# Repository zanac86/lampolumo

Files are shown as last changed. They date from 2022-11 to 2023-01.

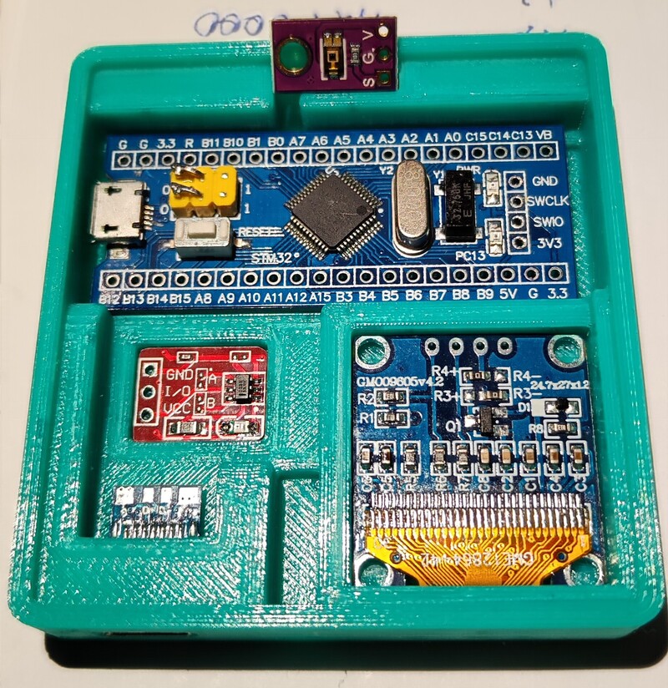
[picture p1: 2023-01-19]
docs/foto1.jpg

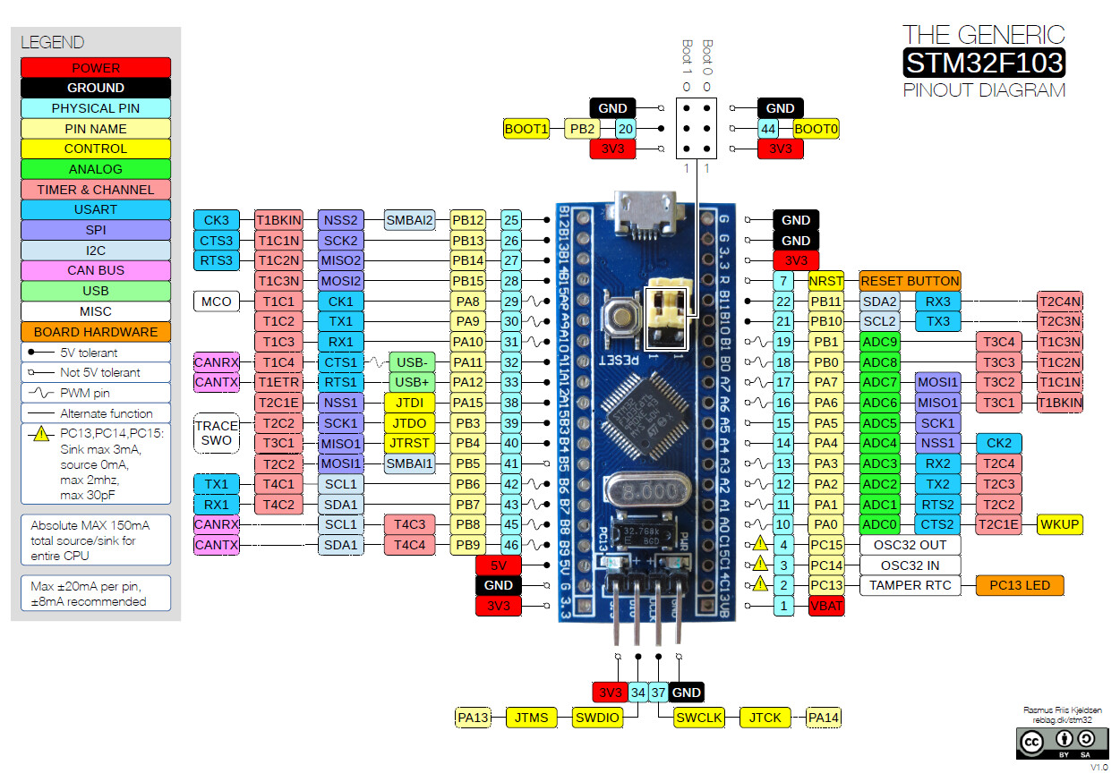
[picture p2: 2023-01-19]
docs/bluepill_pins.jpg

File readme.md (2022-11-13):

# Lampo Lumo (lamp light, esperanto)

Measure pulsation of lamp light

Original project https://mysku.ru/blog/diy/90736.html

## Connection

### OLED SSD1306 display on I2C

| STM | OLED |
|-----|---|
| 3.3 | VDD  |
| GND | GND  |
| B6  | SCK  |
| B7  | SDA  |

### TEMT6000 ambient light sensor to ADC1:0

| STM | TEMT6000 |
|-----|---|
| 5V  | V |
| GND | G |
| A0  | S |

## Firmware upload with `STM32CubeProgrammer`

```
cd /d D:\ST\STM32Cube\STM32CubeProgrammer\bin\
STM32_Programmer_CLI.exe -c port=SWD -d lampo.elf -rst -run
```

## Timings

Ext 8MHz -> HCLK 72 Mhz

APB1 Timer clocks = 72 Mhz
APB2 Timer clocks = 72 Mhz

таймеры TIM2, TIM3, TIM4 работают от APB1 

Это не период между семплами, а время преобразования
зависит от тактовой частоты подаваемой на АЦП
ADC1 = 9 Mhz
а время преобразования задается в тиках этой частоты
ADC1 conversion time - 71.5 cycles - 7,94444 us

BUF - 3000 samples
Sample ADC read period - 100 us - 10 kHz
Fill time - 0.6 s

TIM2 - 1 s

Период между сбором семплов АЦП
TIM3 - 
делители 144-1, 50-1  - 10000 кГц - 100.0 мкс
делители 225-1, 100-1 -  3200 кГц - 312.5 мкс

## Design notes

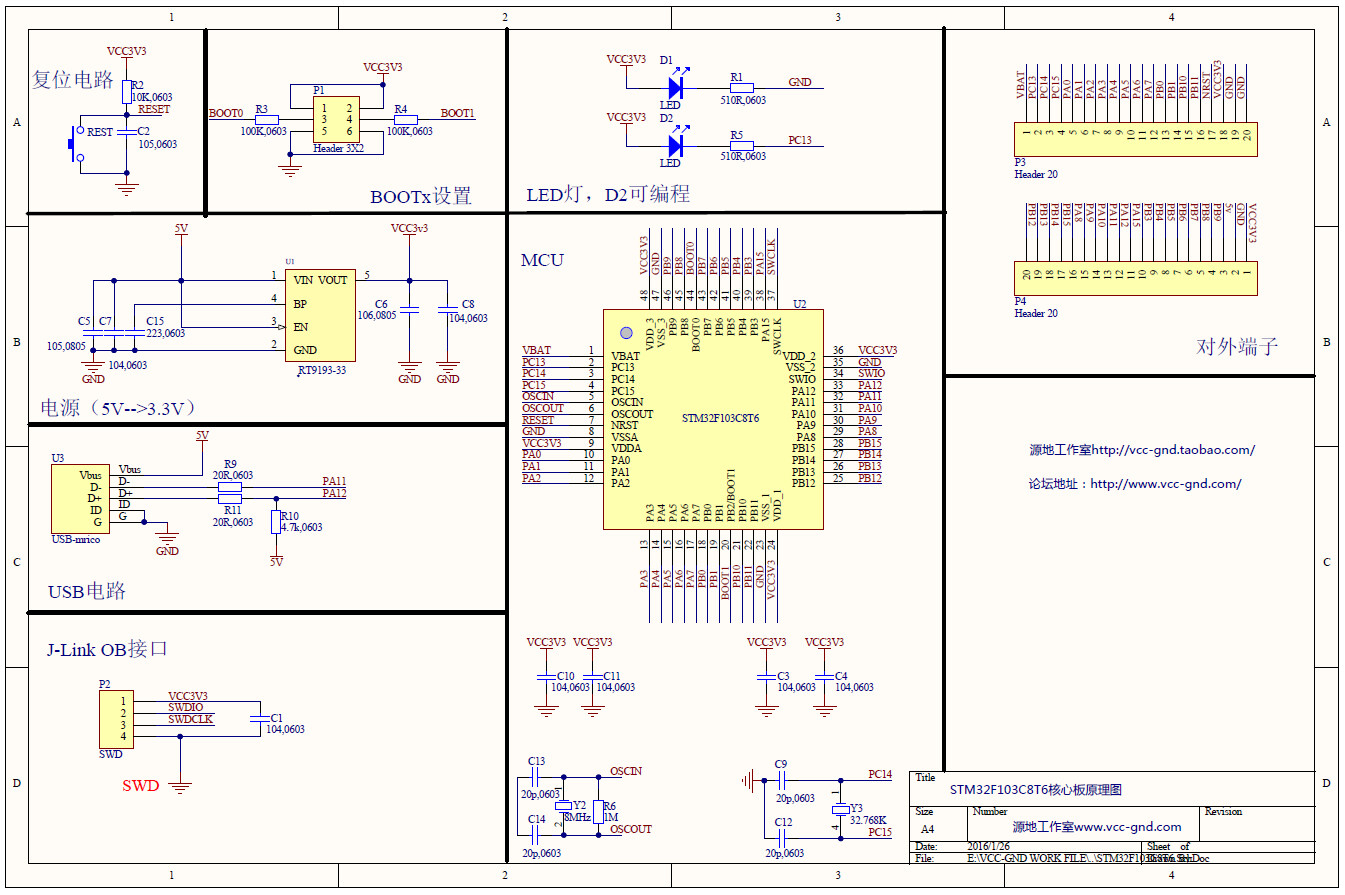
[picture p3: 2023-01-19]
docs/bluepill.jpg

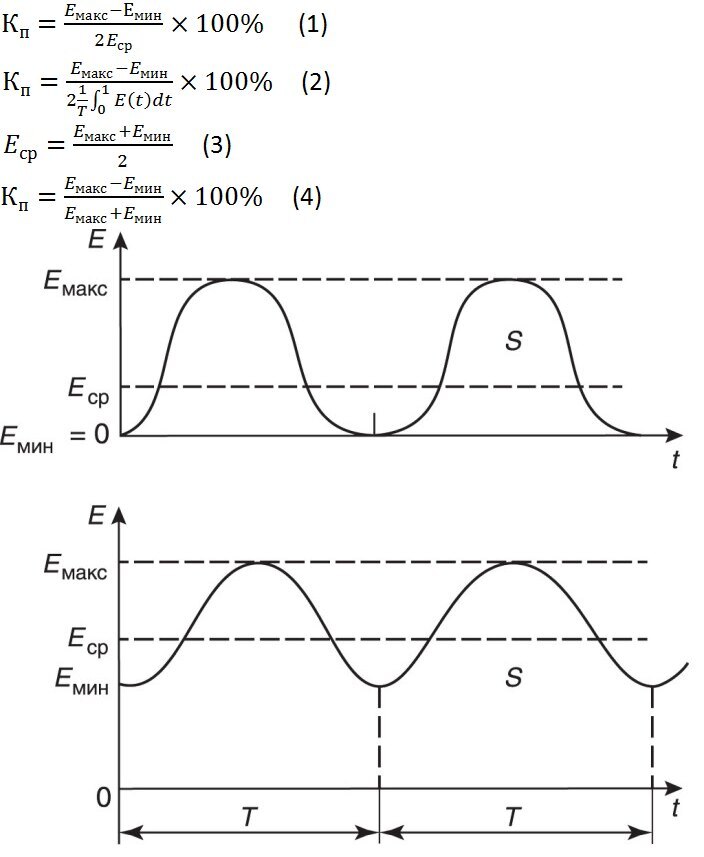
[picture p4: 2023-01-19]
docs/formula.jpg

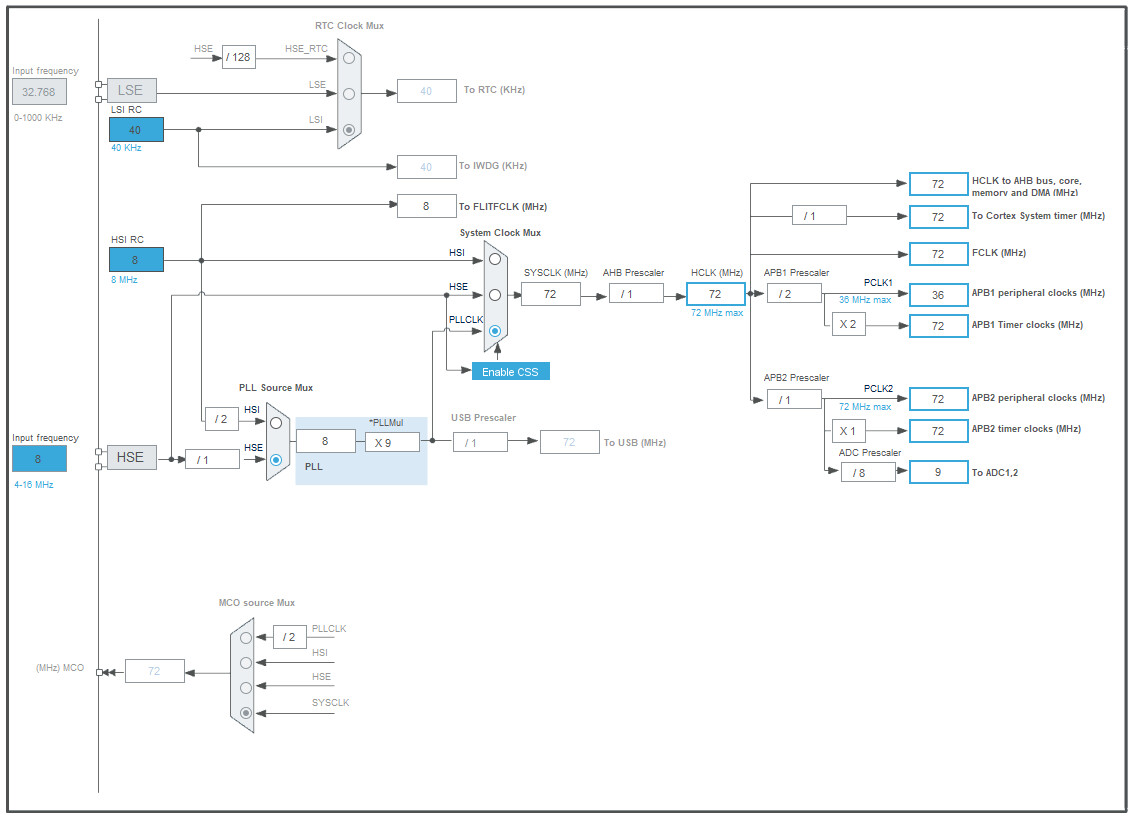
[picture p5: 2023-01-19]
docs/clocks_72mhz.jpg

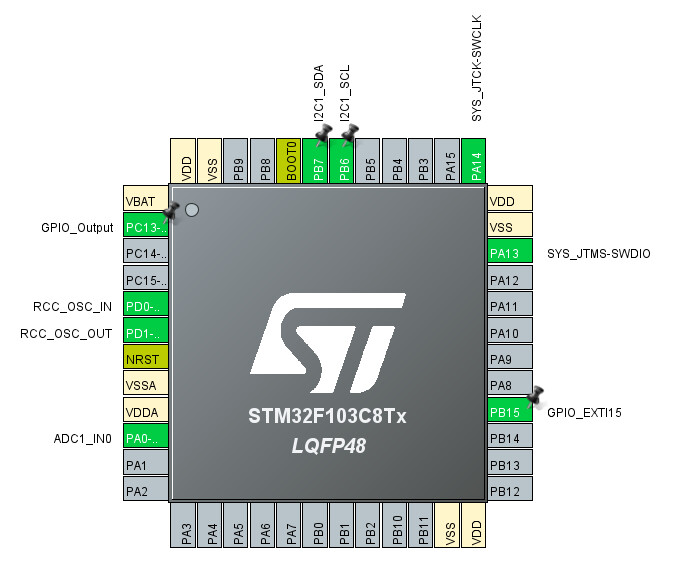
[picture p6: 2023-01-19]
docs/pins.jpg

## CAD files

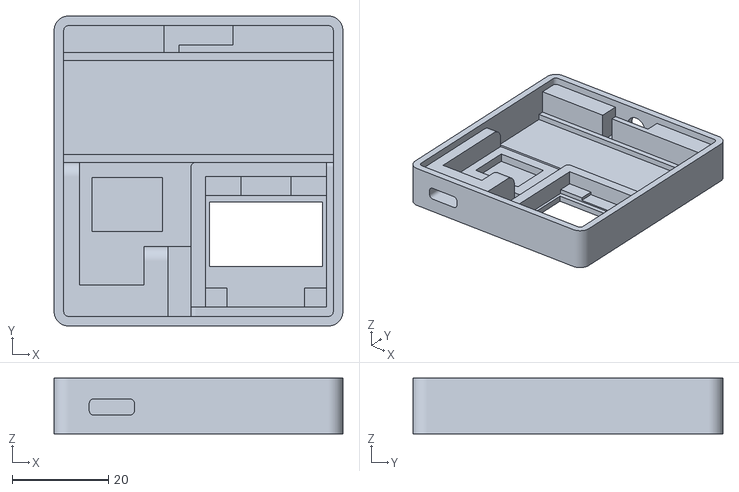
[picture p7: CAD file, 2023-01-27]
box/sensor_box_case.stl
60.0 x 64.4 x 11.6

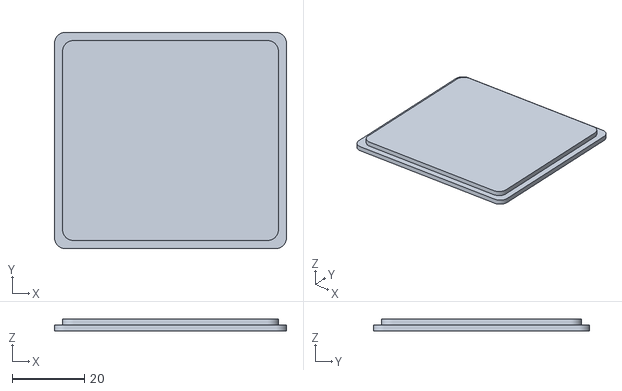
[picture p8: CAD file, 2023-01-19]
box/sensor_box_bottom.stl
64.4 x 60.0 x 3.20

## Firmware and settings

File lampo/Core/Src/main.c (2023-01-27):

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
/* Includes ------------------------------------------------------------------*/
#include "main.h"

/* USER CODE BEGIN Includes */
#include "OLED.h"
#include "checksignal.h"
/* USER CODE END Includes */

ADC_HandleTypeDef hadc1;

I2C_HandleTypeDef hi2c1;

TIM_HandleTypeDef htim2;
TIM_HandleTypeDef htim3;

/* USER CODE BEGIN PV */

SignalInfo signalInfo;

uint16_t adc_count = 0;
volatile uint16_t adc_stopped = 0;
volatile uint16_t new_measure_do = 0;

volatile uint16_t tick1 = 0;

uint16_t decimates[] =
{ 1, 2, 4, 8, 16, 32, 64, 128 };

const uint16_t decimate_max_index = 8;
uint16_t decimate_index = 0;

// 128*32
#define MAX_SAMPLES_COUNT 4096
//#define MAX_SAMPLES_COUNT 3200
//#define MAX_SAMPLES_COUNT 2048
// 3200

// 5120

// Отсчеты АЦП 12 бит 0..4095
// 0-3.3 В

#pragma pack(push, 2)
volatile uint16_t samples[MAX_SAMPLES_COUNT] =
{ 0, };
#pragma pack(pop)

volatile uint16_t sample_index = 0;

volatile uint16_t button_pressed = 0;

/* USER CODE END PV */

void SystemClock_Config(void);
static void MX_GPIO_Init(void);
static void MX_I2C1_Init(void);
static void MX_ADC1_Init(void);
static void MX_TIM3_Init(void);
static void MX_TIM2_Init(void);
/* USER CODE BEGIN 0 */

void HAL_ADC_ConvCpltCallback(ADC_HandleTypeDef *hadc)
{
	// обработчик завершения преобразования ацп
	if (adc_stopped)
	{
		// сейчас пауза на обработку записанного сигнала
		return;
	}

	uint16_t a = HAL_ADC_GetValue(&hadc1);
	if (sample_index > 0)
	{
		// фильтрация=сглаживание
		// (предыдущий+текущий)/2 -> в новый отсчет
		a += samples[sample_index - 1];
		samples[sample_index] = a >> 1;
	}
	else
	{
		samples[sample_index] = a;
	}

	sample_index++;

	if (sample_index == MAX_SAMPLES_COUNT)
	{
		sample_index = 0;
		adc_stopped = 1;
	}
}

void HAL_TIM_PeriodElapsedCallback(TIM_HandleTypeDef *htim)
{
	if (htim->Instance == htim2.Instance)
	{
		// Таймер 2 настроен на 1 сек
		tick1++;
		new_measure_do = 1;
	}
	if (htim->Instance == htim3.Instance)
	{
		// для таймера 3 настроено
		// делители 144-1, 50-1  - 10000 кГц - 100.0 мкс
		// делители 225-1, 100-1 -  3200 кГц - 312.5 мкс
		// -1 в настройках таймера - считает с 0 до N-1 и выдает прерывание
		// и запустим новое преобразование ацп
		HAL_ADC_Start_IT(&hadc1);
	}
}

void init_my_devices()
{
	HAL_Delay(100);
	OLED_Init(&hi2c1);
	OLED_FontSet(Font_MSX_6x8_rus1251);
	OLED_SetContrast(4);
	OLED_Clear(0);
	OLED_DrawStr("STM32F103C8T6", 0, 0, 1);
	OLED_DrawStr(__DATE__, 0, 8, 1);
	OLED_DrawStr(__TIME__, 0, 16, 1);
	char str[20];
	sprintf(str, "S=%ld", HAL_RCC_GetSysClockFreq());
	OLED_DrawStr(str, 0, 24, 1);
	sprintf(str, "H=%ld", HAL_RCC_GetHCLKFreq());
	OLED_DrawStr(str, 64, 24, 1);
	sprintf(str, "1=%ld", HAL_RCC_GetPCLK1Freq());
	OLED_DrawStr(str, 0, 32, 1);
	sprintf(str, "2=%ld", HAL_RCC_GetPCLK2Freq());
	OLED_DrawStr(str, 64, 32, 1);
	OLED_UpdateScreen();
	HAL_Delay(800);
	OLED_Clear(0);
	OLED_UpdateScreen();
}

void print_val(uint8_t line, uint32_t v)
{
	char str[15];
	sprintf(str, "%06lu", v);

	switch (line)
	{
	case 0:
		str[0] = 'A';
		break;
	case 1:
		str[0] = 'X';
		break;
	case 2:
		str[0] = 'N';
		break;
	case 3:
		str[0] = 0x98;
		break;
	case 4:
		str[0] = 'F';
		break;
	case 5:
		str[0] = 'D';
		break;
	case 6:
		str[0] = 'K';
		break;
	case 7:
		str[0] = 'k';
		break;
	}

	OLED_DrawStr(str, OLED_WIDTH - 6 * 6, line * 8, 1);
}

void draw_button_state()
{
	char str[10];
	// если compressed - то узкий символ прямоугольник
	str[0] = button_pressed ? 0x86 : 0x9b;
	str[1] = 0;
	OLED_DrawStr(str, 0, 0, 1);
}

void print_signal(SignalInfo *s)
{
	print_val(0, s->average);
	print_val(1, s->maxCode);
	print_val(2, s->minCode);
	print_val(3, s->range);
	print_val(4, s->freq);
	print_val(5, s->decimated);
	print_val(6, s->kp1);
	print_val(7, s->kp2);

}

void print_ticks()
{
	char str[15];
	sprintf(str, "%06u", tick1);
	OLED_DrawStr(str, 0, 56, 1);
}

void draw_waveform()
{
//	decimate_index = (tick1 / 2) % 6;
	signalInfo.decimated = decimates[decimate_index];
	process_adc(&signalInfo, samples, MAX_SAMPLES_COUNT);
	OLED_Clear(0);
	for (uint16_t i = 0; i < signalInfo.show_samples; i++)
	{
		OLED_DrawPixel(i, OLED_HEIGHT - samples[i] - 1);
	}

	print_signal(&signalInfo);
	print_ticks();
	OLED_UpdateScreen();
}

void print_val_zoom(char c, uint32_t v, uint8_t x, uint8_t y, uint8_t zoom)
{
	char str[15];
	sprintf(str, "%4lu", v);
	str[0] = c;

	OLED_DrawStrZoom(str, x, y, 1, zoom);
}

void draw_big_numbers()
{
	signalInfo.decimated = decimates[decimate_index];
	process_adc(&signalInfo, samples, MAX_SAMPLES_COUNT);
	OLED_Clear(0);

	char str[15];
	sprintf(str, "Kp %3u %%", signalInfo.kp1);
	OLED_DrawStrZoom(str, 4, 3, 1, 2);

	sprintf(str, "Fr %4u Hz", signalInfo.freq);
	OLED_DrawStrZoom(str, 4, 24, 1, 2);

	OLED_DrawRectangle(0, 0, 127, 21);
	OLED_DrawRectangle(0, 21, 127, 42);
	OLED_DrawRectangle(0, 42, 127, 63);

	sprintf(str, "%4u Min", signalInfo.minCode);
	OLED_DrawStrZoom(str, 4, 45, 1, 1);
	sprintf(str, "%4u Max", signalInfo.maxCode);
	OLED_DrawStrZoom(str, 4, 54, 1, 1);

	sprintf(str, "%4u Av", signalInfo.average);
	OLED_DrawStrZoom(str, 70, 45, 1, 1);
	sprintf(str, "%4u \x98", signalInfo.range);
	OLED_DrawStrZoom(str, 70, 54, 1, 1);

	OLED_UpdateScreen();
}

/* USER CODE END 0 */

/**
 * @brief  The application entry point.
 * @retval int
 */
int main(void)
{
	/* MCU Configuration--------------------------------------------------------*/

	/* Reset of all peripherals, Initializes the Flash interface and the Systick. */
	HAL_Init();

	/* Configure the system clock */
	SystemClock_Config();

	/* Initialize all configured peripherals */
	MX_GPIO_Init();
	MX_I2C1_Init();
	MX_ADC1_Init();
	MX_TIM3_Init();
	MX_TIM2_Init();
	/* USER CODE BEGIN 2 */

	init_my_devices();

	HAL_ADCEx_Calibration_Start(&hadc1);

	HAL_TIM_Base_Start_IT(&htim2);
	HAL_TIM_Base_Start_IT(&htim3);

	HAL_Delay(100);

	/* USER CODE END 2 */

	/* Infinite loop */
	/* USER CODE BEGIN WHILE */
	while (1)
	{
//		HAL_Delay(1);
		if (new_measure_do == 1)
		{
			new_measure_do = 0;
		}
		if (adc_stopped)
		{
			HAL_GPIO_WritePin(GPIOC, GPIO_PIN_13, GPIO_PIN_RESET);
			if (decimate_index == (decimate_max_index - 1))
			{
				draw_big_numbers();
			}
			else
			{
				draw_waveform();
			}
			sample_index = 0;
			adc_stopped = 0;
			HAL_GPIO_WritePin(GPIOC, GPIO_PIN_13, GPIO_PIN_SET);
		}

		if (button_pressed)
		{
			draw_button_state();
			OLED_UpdateScreen();
			button_pressed = 0;
			decimate_index = (decimate_index + 1) % decimate_max_index;
		}

		/* USER CODE END WHILE */

		/* USER CODE BEGIN 3 */
	}
	/* USER CODE END 3 */
}

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
/* USER CODE BEGIN 4 */
void HAL_GPIO_EXTI_Callback(uint16_t GPIO_Pin)
{
	if (GPIO_Pin == GPIO_PIN_15)
	{
		button_pressed = 1;
	}
}
/* USER CODE END 4 */
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


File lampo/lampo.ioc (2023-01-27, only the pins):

Mcu.UserName=STM32F103C8Tx
PA0-WKUP.Signal=ADCx_IN0
PB15.Signal=GPXTI15
PB6.Signal=I2C1_SCL
PB7.Signal=I2C1_SDA
PC13-TAMPER-RTC.Signal=GPIO_Output
PD0-OSC_IN.Signal=RCC_OSC_IN
PD1-OSC_OUT.Signal=RCC_OSC_OUT

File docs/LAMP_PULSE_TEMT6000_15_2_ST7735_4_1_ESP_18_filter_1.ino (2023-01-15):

/*


https://mysku.club/blog/diy/90736.html

*/


//#include <UTFTGLUE.h>              //use GLUE class and constructor
#include <Adafruit_GFX.h>
#include <Adafruit_ST7735.h>
#include <SPI.h>
#include <ESP8266WiFi.h>
#include <GyverFilters.h>

#define ANALOG_IN_PIN A0 //A5  //Light Sensor pin

#define ENV_MEASURE_PIN D4 //9 //button

#define TOP_HEIGHT_DISPLAY 40
#define BOTTOM_HEIGHT_DISPLAY 60
#define LCD_X_WIDTH 127
#define LCD_Y_HEIGHT 159

#define LIMIT_MAX_ENV_ILLUMINANCE 80 //1023
#define LIMIT_MIN_ILLUMINANCE 150 //1023
#define LIMIT_MAX_ILLUMINANCE 950 //1023

#define ENV_NUMBER_CALIBRATION_MEASURES 500 //one measure per ENV_MEASURE_INTERVAL
#define ENV_MEASURE_INTERVAL 1 //ms

#define PRINT_INFO_INTERVAL 1000 //ms

#define X_POS_PRINT 3

//UTFTGLUE myGLCD(0,A2,A1,A3,A4,A0); //all dummy args

// TFT display and SD card will share the hardware SPI interface.
// Hardware SPI pins are specific to the Arduino board type and
// cannot be remapped to alternate pins.  For Arduino Uno,
// Duemilanove, etc., pin 11 = MOSI, pin 12 = MISO, pin 13 = SCK.
//#define SD_CS    4  // Chip select line for SD card
#define TFT_CS   D2 //10  // Chip select line for TFT display
#define TFT_DC   D1 //8  A0  // Data/command line for TFT 
#define TFT_RST  D6 //-1  // Reset line for TFT (or connect to +5V)

#define ST7735_DARKGRAY 0x7BEF

Adafruit_ST7735 tft = Adafruit_ST7735(TFT_CS, TFT_DC, TFT_RST);

long timer_1 = 0;
long timer_2 = 0;
long timer_3 = 0;
long timer_4 = 0;
long timer_5 = 0;

float a_val = 0.0;
int n = 0;
int m = 0;

int x = 0;
int y = 0;

bool arr_filled = false;

//int point_arr[400] = {}; //2.4"
int point_arr[160] = {}; //1.8"
int mid_point_arr[160] = {};
int point_arr_filt[160] = {};

byte n_rise = 0;
byte n_fall = 0;

byte x1_min = 0;
byte x1_max = 0;

int y_1 = 0;
int y_2 = 0;
int y_3 = 0;

float kp1 = 0;
float kp2 = 0;

long sum_E = 0;
int env_E = 0; //5
long env_E_sum = 0;
int Emax = 0;
int Emin = 0;

int delta_y = 40;
int y_min = 0;

int Emax_sum = 0;
int Emin_sum = 0;
int sum_E_sum = 0;
int n_m = 0;

long timer_print = 0;

int y_1_1 = 0;
int y_1_2 = 0;

int y_2_1 = 0;
int y_2_2 = 0;

//GFilterRA analog0;
GKalman kalman(90, 90, 0.5);
GFilterRA average(0.5, 80);

void setup()
{

    WiFi.mode(WIFI_OFF);
    WiFi.forceSleepBegin();

    Serial.begin(115200);
    pinMode(ANALOG_IN_PIN,  INPUT);
    pinMode(ENV_MEASURE_PIN, INPUT_PULLUP);

    randomSeed(analogRead(0));
    /*
    // Setup the LCD
    myGLCD.InitLCD();
    myGLCD.setFont(BigFont); //SmallFont
    myGLCD.setTextSize(5);

    //myGLCD.setColor(127,127,127);
    myGLCD.setColor(0, 0, 0);
    myGLCD.fillRect(0, 0, 319, 239);*/

    // Initialize 1.8" TFT 128x160
    tft.initR(INITR_BLACKTAB);   // initialize a ST7735S chip, black tab
    tft.setRotation(0);

    Serial.println("1.8 TFT OK!");
    tft.fillScreen(ST7735_BLACK);

    tft.setTextSize(1); //1 2 3
    tft.setTextColor(ST7735_WHITE, ST7735_BLACK);


    tft.setCursor(30, 0);
    tft.print("LAMPTEST.RU");

    tft.setCursor(0, 150);
    tft.print("Flicker test v0.18_f");

    tft.setCursor(15, 75);
    tft.print("Auto calibration");


    delay(1000);

    Serial.println("Start measure Eenv. It will take about " + String(ceil(ENV_NUMBER_CALIBRATION_MEASURES / 1000.0)) + " seconds");
    //Eenv measure
    while (m < ENV_NUMBER_CALIBRATION_MEASURES)
    {
        if (millis() > (timer_5 + ENV_MEASURE_INTERVAL))
        {
            timer_5 = millis();
            m++;
            //env_E_sum += analogRead(ANALOG_IN_PIN);
            int a_val = analogRead(ANALOG_IN_PIN);
            env_E_sum += a_val;
            Serial.println(a_val);
        }
    }
    env_E = int((float) env_E_sum / (float) ENV_NUMBER_CALIBRATION_MEASURES);
    Serial.println("env_E_sum: " + String(env_E_sum) + " env_E: " + String(env_E));

    tft.fillScreen(ST7735_BLACK);

    //  analog0.setCoef(1.0); // установка коэффициента фильтрации (0.0... 1.0). Чем меньше, тем плавнее фильтр
    //  analog0.setStep(312.5); // установка шага фильтрации (мс). Чем меньше, тем резче фильтр


}

long start_time = 0;
//long finish_time = 0;

void loop()
{

    //1.8" 128x160 128/4=32*5=160  4 periods x 32 points = 128 pts   100 Hz x 32 values   1000000/3200 = 312.5 mcs
    //2.4" 320x240 320/4=80*5=400  4 periods x 80 points = 320 pts   100 Hz x 80 values   1000000/8000 = 125 mcs


    //if (micros() > (timer_2 + 125))
    if (micros() > (timer_2 + 312.5))
    {
        timer_2 = micros();
        //if (x < 400)
        if (x < 160)
        {
            point_arr[x] = analogRead(ANALOG_IN_PIN);
            //point_arr_filt[x] = analog0.filteredTime(point_arr[x]);
            //point_arr_filt[x] = (int)kalman.filtered(point_arr[x]);
            point_arr_filt[x] = (int)average.filtered(point_arr[x]);
            if (x > 0)
            {
                mid_point_arr[x] = (point_arr[x - 1] + point_arr[x]) / 2;
            }
            x++;
        }
        else
        {
            arr_filled = true;
            x = 0;
            start_time = millis();
        }
    }

    if (arr_filled == true)
    {
        /*if (digitalRead(ENV_MEASURE_PIN) == LOW)
        {
          if (millis() > (timer_4 + 1000))
          {
            timer_4 = millis();
            env_E = analogRead(ANALOG_IN_PIN);
          }
        }*/

        //find max min
        sum_E = point_arr[0];
        x1_max = 0;
        x1_min = 0;
        //for (int x1 = 1; x1 <80; x1++)
        for (int x1 = 1; x1 < 32; x1++)
        {
            sum_E += point_arr[x1] - env_E;

            if (point_arr[x1] > point_arr[x1_max])
            {
                x1_max = x1;
            }

            if (point_arr[x1] < point_arr[x1_min])
            {
                x1_min = x1;
            }
        }

        delta_y = 40 * ceil((point_arr[x1_max] - point_arr[x1_min]) / 40.0);
        y_min = point_arr[x1_max] - delta_y;
        //Serial.println(y_min);
        if (y_min < 0)
        {
            y_min = 0;

        }

        /*
        _mid = point_arr[x1_max]
        point_arr[x1_min]
        sum_E_mid
        */
        Emax_sum += point_arr[x1_max];
        Emin_sum += point_arr[x1_min];
        sum_E_sum += sum_E;
        n_m++;
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

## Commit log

2022-03-27 Lampo Lumo - measure pulsation of lamp light
    [hz.xlsx]
2022-03-28 Timers test
    [hz.xlsx]
2022-04-01 Getting ADC samples with DMA
    [hz.xlsx]
2022-04-03 ADC dump
2022-04-10 Get samples on timer 5000Hz
    [hz.xlsx]
2022-04-12 Getting real waveform
    [hz.xlsx]
2022-06-15 Begin calculate Kp
    [hz.xlsx]
2022-11-13 Calculating Kpulse
    [hz.xlsx]
2023-01-15 Корпус и надо обработать кнопку
    [hz.xlsx]
2023-01-16 Поправил расчет среднего
2023-01-19 По кнопке переключается прореживание
    [hz.xlsx, sensor_box_bottom.stl, sensor_box_case.stl]
2023-01-27 Экран с крупными цифрами
    [sensor_box_case.stl]

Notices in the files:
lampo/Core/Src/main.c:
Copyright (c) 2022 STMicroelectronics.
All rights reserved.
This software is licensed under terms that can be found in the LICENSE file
